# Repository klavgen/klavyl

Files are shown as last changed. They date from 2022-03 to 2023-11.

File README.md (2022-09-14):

# Klavyl: handwired mechanical keyboard

<p align="center">
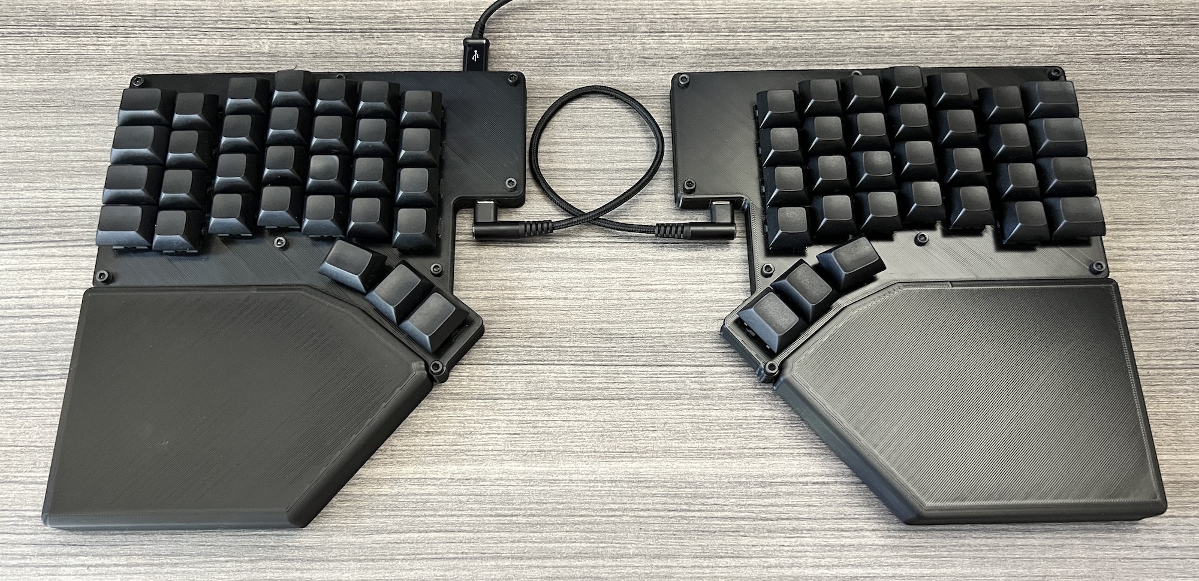
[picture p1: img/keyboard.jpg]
Klavyl keyboard

</p>

**Klavyl** is a [Klavgen](https://github.com/klavgen/klavgen)-based, handwired, hotswappable, split, ortholinear,
3D-printed, highly composable mechanical keyboard that has 4 rows and 7 columns, a 3-key thumb fan, is easy to solder,
is low height, and has a palm rest. That's a lot, so let's decompose:

- **handwired**: you don't need to buy or make PCBs
- **MX or Choc switches**: uses either MX or Choc switches (but with MX spacing). Choc is still highly experimental.
- **hotswappable**: uses Kailh hotswap sockets
- **split**: left and right hand halves are separate
- **ortholinear**: keys form a line across rows, rather than staggered where each row is offset
- **3D-printed without supports** on a home FDM printer, with large parts kept simple to minimize the chance of errors
- **low height**: only 11 mm tall, including 2mm top and bottom plates
- **highly composable**: small changes to the layout only require printing a top plate since the switch holders can be
  moved and the wrapped wires can be unwrapped to allow keys to be spaced further apart
- **easy to solder**: uses holders for the Kailh hotswap sockets that allow in-place soldering of the Kailh socket,
  diode and wires; supports bare wires without insulation, because stripping wires is a pain
- **sturdy**: the Kailh socket holders support the top plate to prevent bending
- **4 rows and 7 columns, plus a 3-key thumb fan**: 31 keys per half, 62 total
- **parametrically generated with [Klavgen](https://github.com/klavgen/klavgen)**
- **palm rests**: detachable and optional

I made Klavyl as a personal modification of the excellent [Redox keyboard](https://github.com/mattdibi/redox-keyboard).

The current files are meant for:

- Kailh hotswap sockets (MX or Choc)
- Pro Micro or similar boards of the same size
- USB-C connection between the two halves
- QMK for the firmware
- Printing on a reasonably tuned 3D printer. I used an Ender 3 V2.
- M3 screws with inserts that are melted into the board

If you want a different config, let me know by filing an issue.

# STLs

You can find STLs in:

- [`/stl_mx`](stl_mx/) for MX switches
- [`/stl_choc`](stl_choc/) for Choc switches (highly experimental)

# More pictures of the MX version

Back photo, showing the low height of 11 mm and the cable connections:

<p align="center">
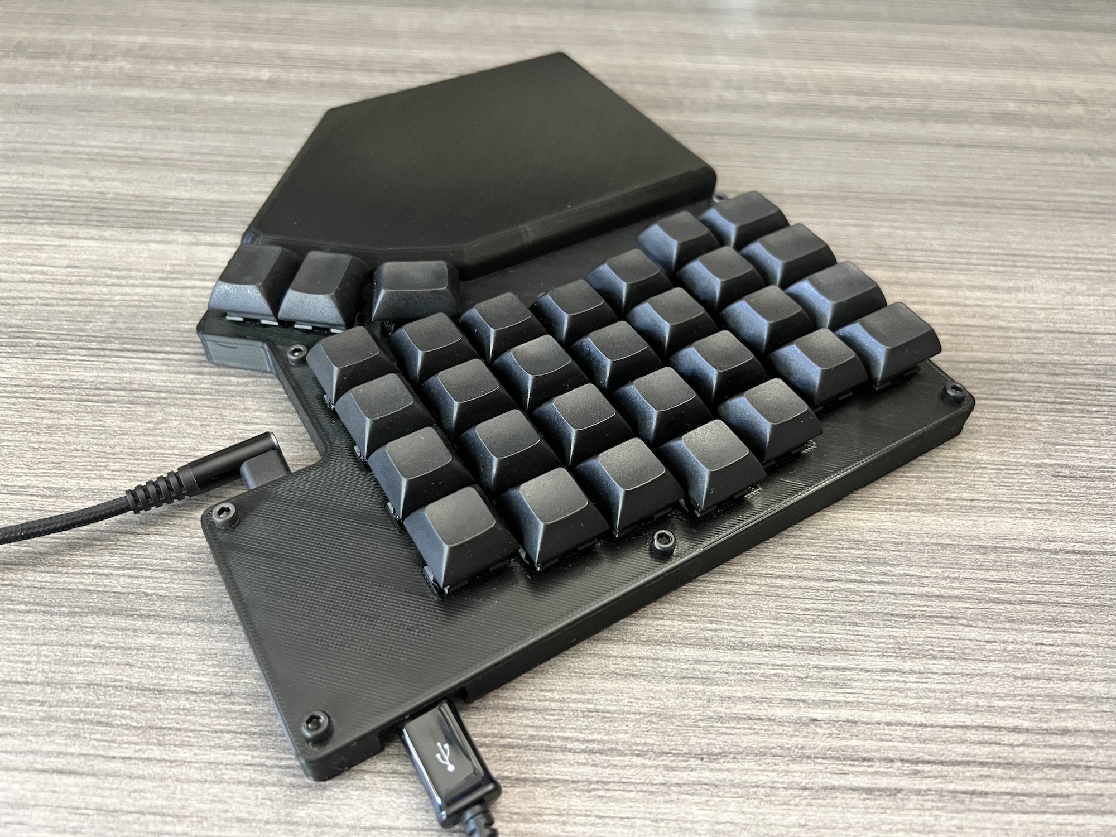
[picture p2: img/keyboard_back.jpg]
Klavyl keyboard

</p>

Front of 3D model, showing the top with switch holes, the bottom, the palm rest, and the USB-C jack holder:

<p align="center">
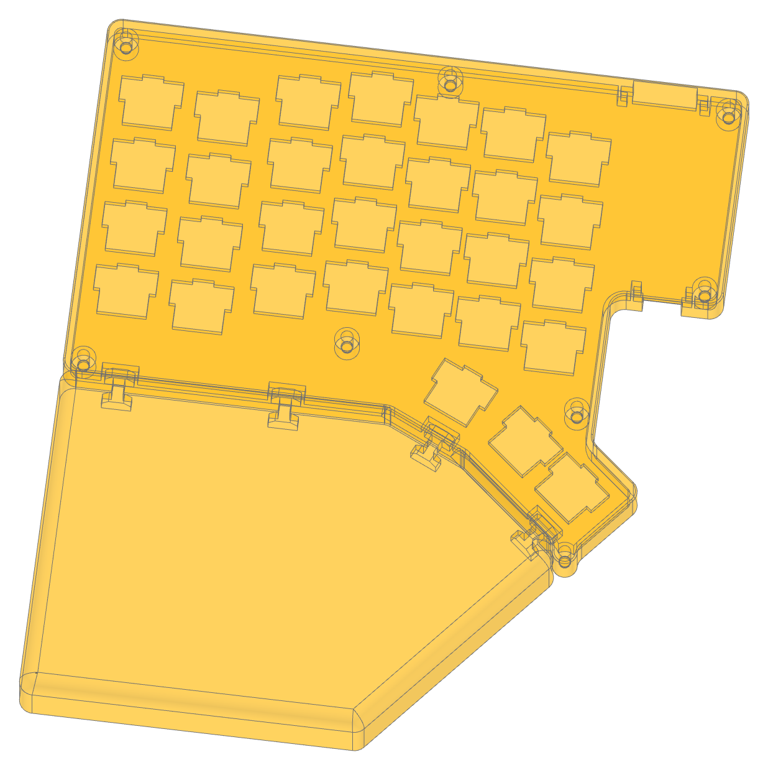
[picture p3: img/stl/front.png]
Front

</p>

Back of 3D model, showing the cutout for the Pro Micro:

<p align="center">
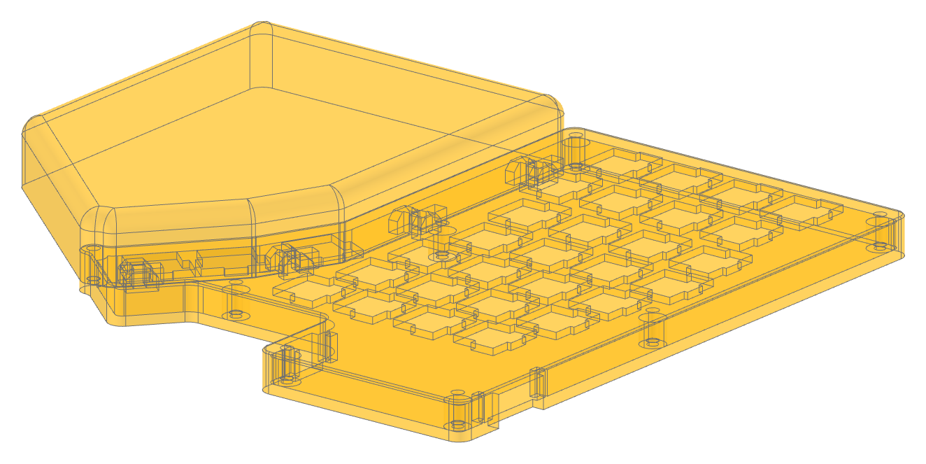
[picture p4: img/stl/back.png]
Back

</p>

Front of 3D model, showing all the components (top, bottom, palm rest, switch holders, Pro Micro holder, USB-C jack
holder):

<p align="center">
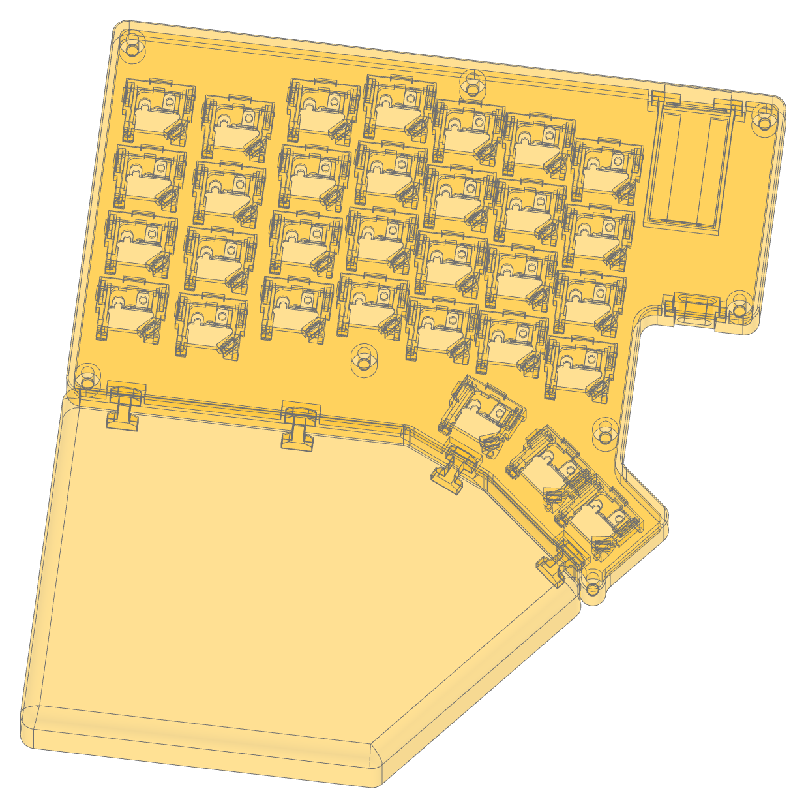
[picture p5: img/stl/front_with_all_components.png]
Front with all components

</p>

# Generating STLs and adjusting the layout

To see how Klavyl is built and adjust it, as well as re-generate the output `.stl` files (from the `stl` directory),
check out and run the [`klavyl.py`](klavyl.py) file.

Modify the `use_choc` variable to generate Choc holes and switch holders.

# Purchased parts

These are the parts you need. The Amazon links is what I used and they are non-affiliate.

| Quantity | Part | Notes |
| ---: | --- | --- |
| 62 | MX switches | I use Boba U4, from AliExpress |
| 62 | MX keycaps | 48 1u keycaps and 14 1.25u keycaps |
| 62 | Kailh hotswap sockets | [Amazon link](https://www.amazon.com/gp/product/B096WZ6TJ5) for MX; the Choc hotswap sockets I got from AliExpress |
| 62 | 1N4148 diodes | [Amazon link](https://www.amazon.com/gp/product/B06XB1R2NK) |
| 2 | Female USB-C socket | [Adafruit link](https://www.adafruit.com/product/5180) |
| 2 | 4.7 kOhm resistors | [Amazon link](https://www.amazon.com/gp/product/B07HDFHPP3) |
| 2 | Arduino Pro Micro microcontrollers | [Amazon link](https://www.amazon.com/gp/product/B08BJNV1J3) |
| 1 | USB-C to USB-C cable | [Amazon link](https://www.amazon.com/gp/product/B0B5QJTT8M) |
| 1 | Micro USB cable | Make sure it's not a power-only cable |
|  20 feet | 26 gauge or smaller solid core wire | You can also use enameled or stranded wires, but it will be more painful |
| ~20 | Rubber bumpers to stabilize the board | [Amazon link](https://www.amazon.com/gp/product/B08MDW52SC) |
| 12 | M3 6 or 8 mm screws | [Amazon link](https://www.amazon.com/gp/product/B07VRC5RJ8) |
| 12 | M3 inserts | [Amazon link](https://www.amazon.com/gp/product/B01IYWTCWW) |
| Much | PLA for 3D printing most parts | I used a mix of Hatchbox and Overture, but any should do |
| Some | ABS for 3D printing switch holders | I used Hatchbox |

# Tools

You need:

- Soldering iron and everything around it: solder, safety glasses, ventilation, etc.
- Tweezers
- Wire stripper, unless you are going to strip manually or will use bare wire for the rows/columns and only use
  insulated wire for the Pro Micro and USB-C jacks

# 3D printed parts

All the parts for 3D printing are in the [`stl_mx`](stl_mx/)/[`stl_choc`](stl_choc/) directories. They have been tested
on an Ender 3 V2 and therefore the tolerances may not work for your printer. If that's the case, let me know by filing
an issue in the project.

Below I discuss MX version, but everything is the same for the Choc versions in the [`stl_choc`](stl_choc/) directory.

You should be able to print everything in PLA, expect the switch holders for which I recommend ABS because you'll be
soldering on them and the soldering iron can very easily melt PLA.

This is what you should print:

| Quantity | File | Notes |
| ---: | --- | --- |
| 1 | `keyboard_top.stl` | Print in normal orientation for the left hand |
| 1 | `keyboard_top.stl` | Print **mirrored** for right hand |
| 1 | `keyboard_bottom.stl` | Print in normal orientation for the left hand |
| 1 | `keyboard_bottom.stl` | Print **mirrored** for right hand |
| 1 | `palm_rest.stl` | Print in normal orientation for the left hand |
| 1 | `palm_rest.stl` | Print **mirrored** for right hand |
| 62 | `switch_holder.stl` | Print file as is, without supports, with the flat side facing down. Use ABS |
| 4 | `connector.stl` | Print file as is, without supports |
| 2 | `controller_holder.stl` | Ensure your Pro Micros actually fit |
| 2 | `usbc_jack_holder.stl`  | Ensure your USB-C jacks actually fit |

## Keyboard bottom

File [`keyboard_bottom.stl`](stl_mx/keyboard_bottom.stl). The bottom part, for the left hand.

<p align="center">
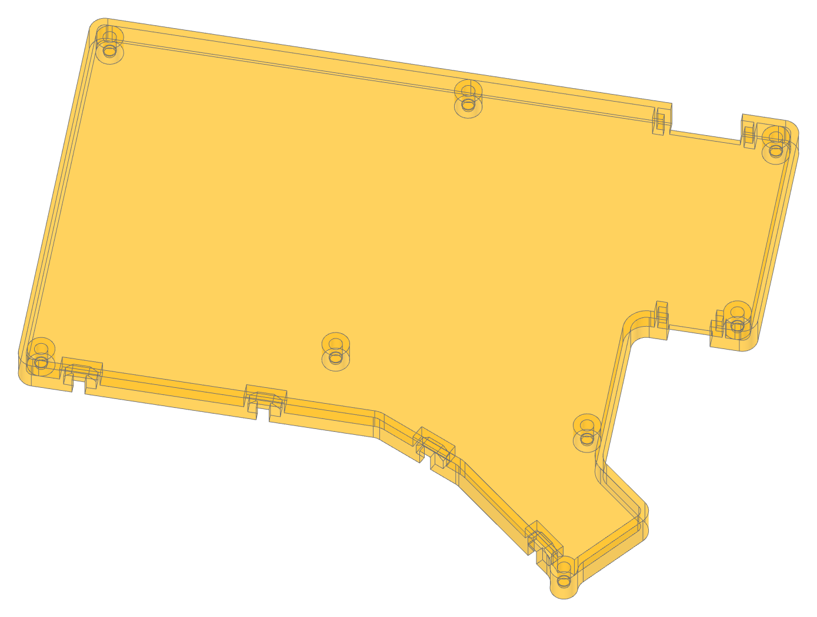
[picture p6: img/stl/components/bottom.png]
Bottom

</p>

## Keyboard top

File [`keyboard_top.stl`](stl_mx/keyboard_top.stl). The top plate, for the left hand. It is flat with simple holes so
that it can be made with a laser cutter or a CNC machine

<p align="center">
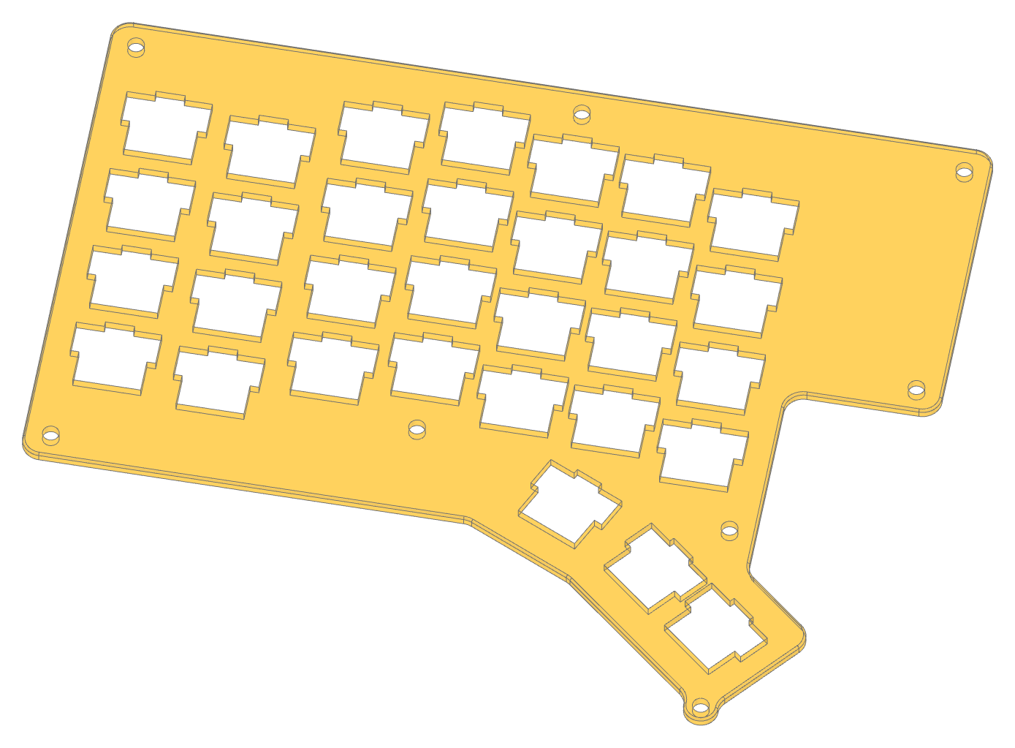
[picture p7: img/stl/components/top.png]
Top

</p>

## Palm rest

File [`palm_rest.stl`](stl_mx/palm_rest.stl). The palm rest which attaches to the bottom via connectors. It can also be
fused with the bottom, see below.

<p align="center">
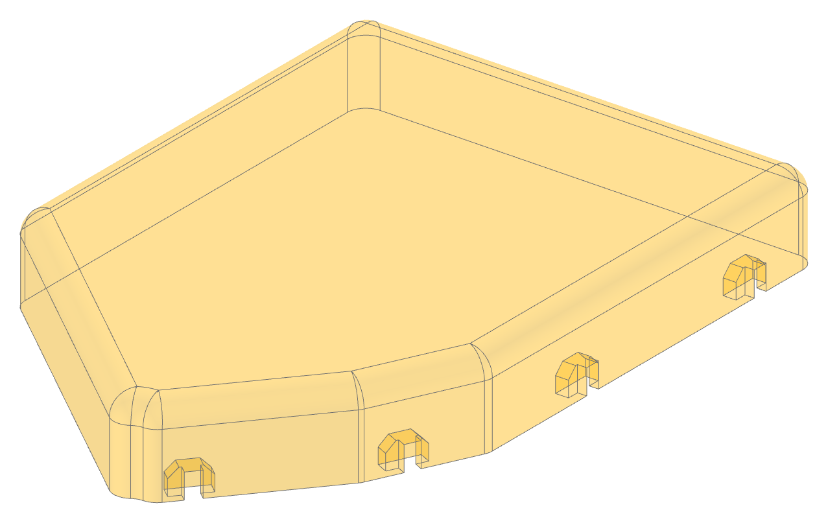
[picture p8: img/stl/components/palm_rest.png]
Palm rest

</p>

## Switch holder

File [`switch_holder.stl`](stl_mx/switch_holder.stl). Holds the Kailh MX hotswap socket and allows you to solder the
diode, column and row wires in-place. Print it the way it's oriented in the STL, with the flat side (that has a small
hole) on the printing plate.

**Note**: print switch holders in ABS since you'll be soldering on them.

<p align="center">
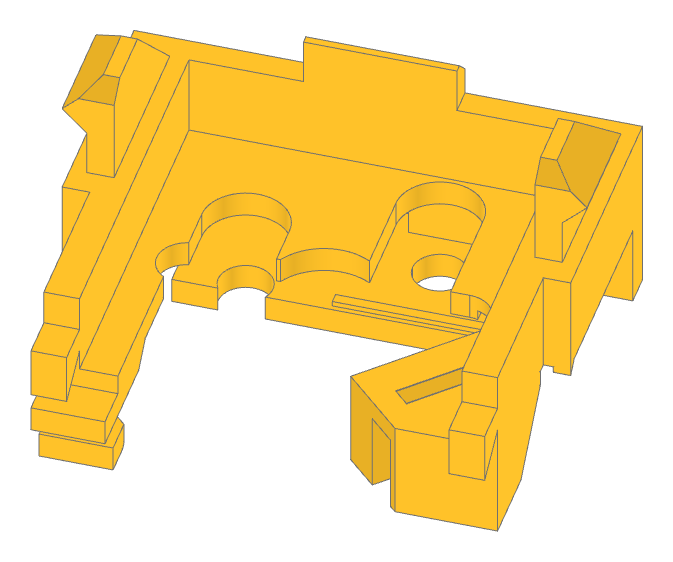
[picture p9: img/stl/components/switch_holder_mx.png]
Switch holder

</p>

## Pro Micro controller holder

File [`controller_holder.stl`](stl_mx/controller_holder.stl). Holds the Arduino Pro Micro controller.

<p align="center">
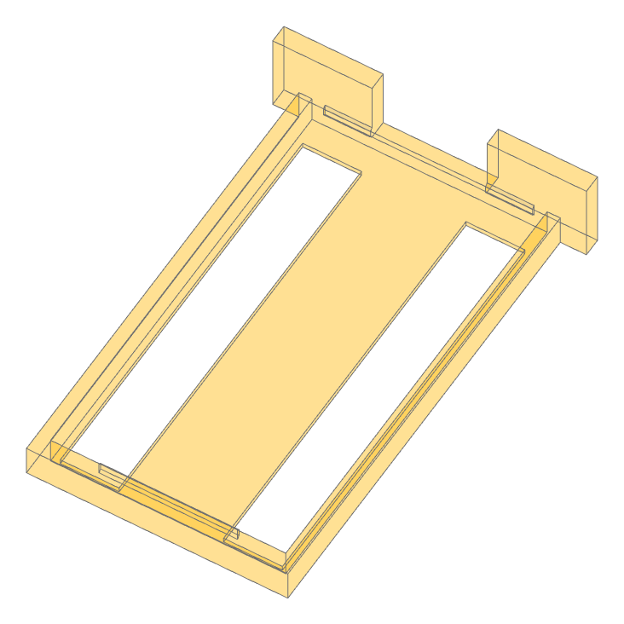
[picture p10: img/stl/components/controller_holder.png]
Pro Micro holder

</p>

## USB-C jack holder

File [`usbc_jack_holder.stl`](stl_mx/usbc_jack_holder.stl). Holds the USB-C socket.

<p align="center">
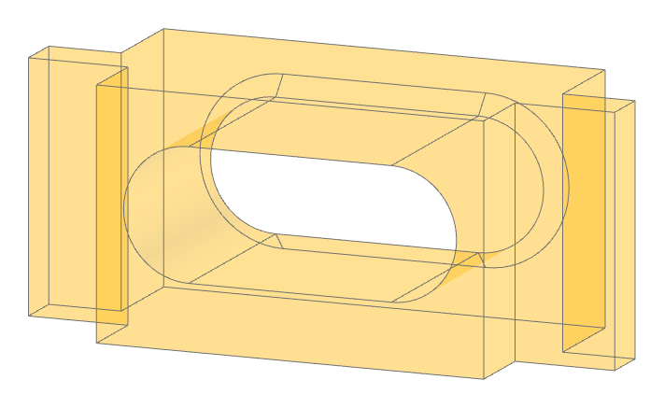
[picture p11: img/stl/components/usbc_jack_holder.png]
USBC jack holder

</p>

## Connector

File [`connector.stl`](stl_mx/connector.stl). Connects the bottom to the palm rest.

<p align="center">
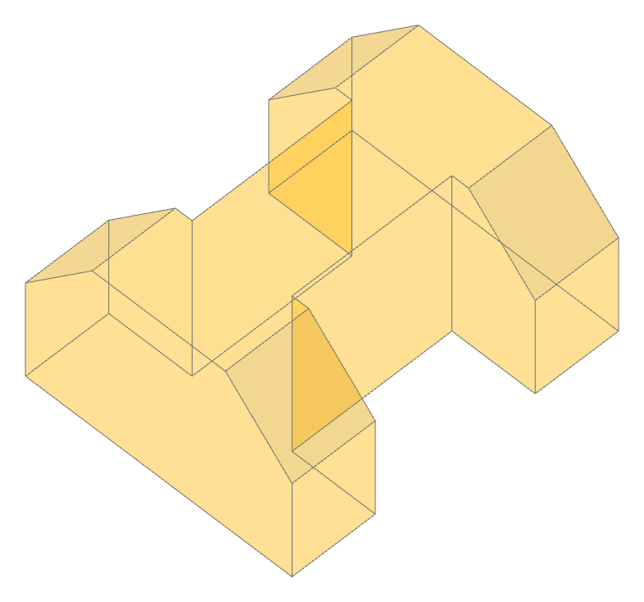
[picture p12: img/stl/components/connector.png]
Connector

</p>

# Building

## Build the left side

1. Strip wires completely for rows and columns, making sure they are about 2x the size of the plate due to wrapping. Do
   not leave insulated wire at the end like I did.

1. Row by row, insert the socket holders, and wrap the row wires:

<p align="center">
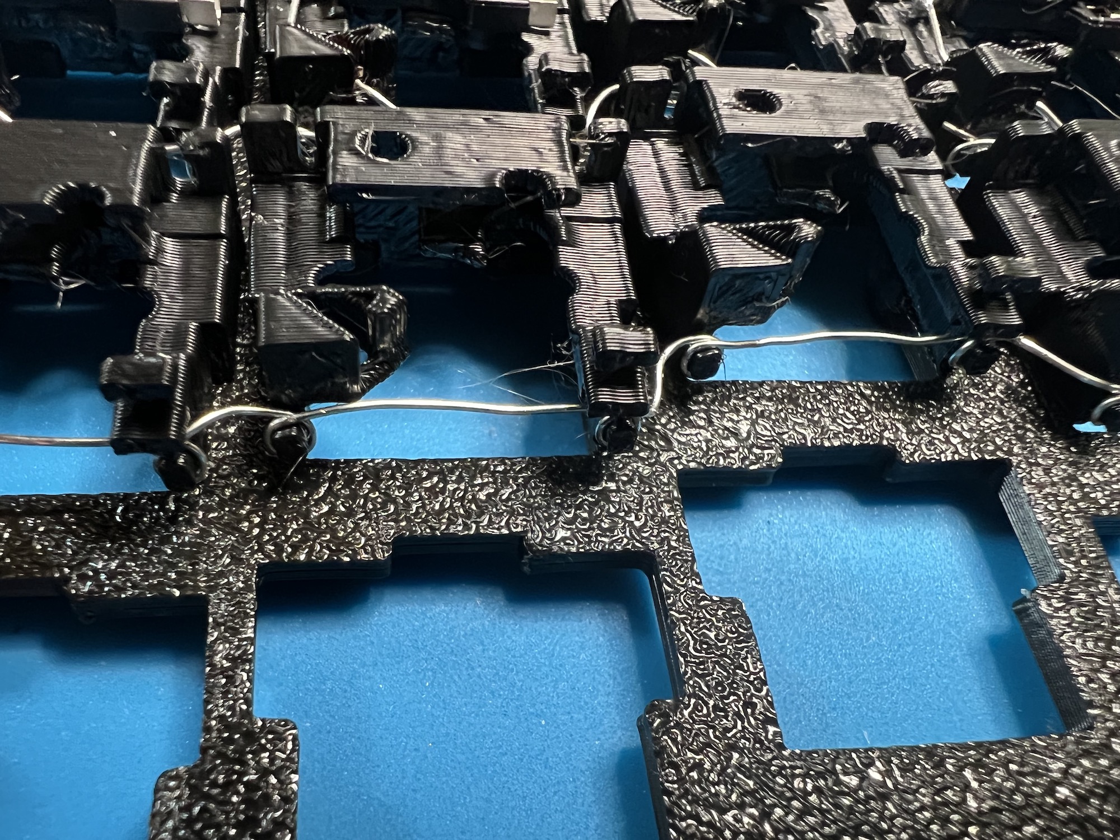
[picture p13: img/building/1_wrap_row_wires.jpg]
Wrap row wires

</p>

**Note**: the 3 keys on the thumb fan are a separate row

3. Place the diodes, bending the legs on the back to hold them in place:

<p align="center">
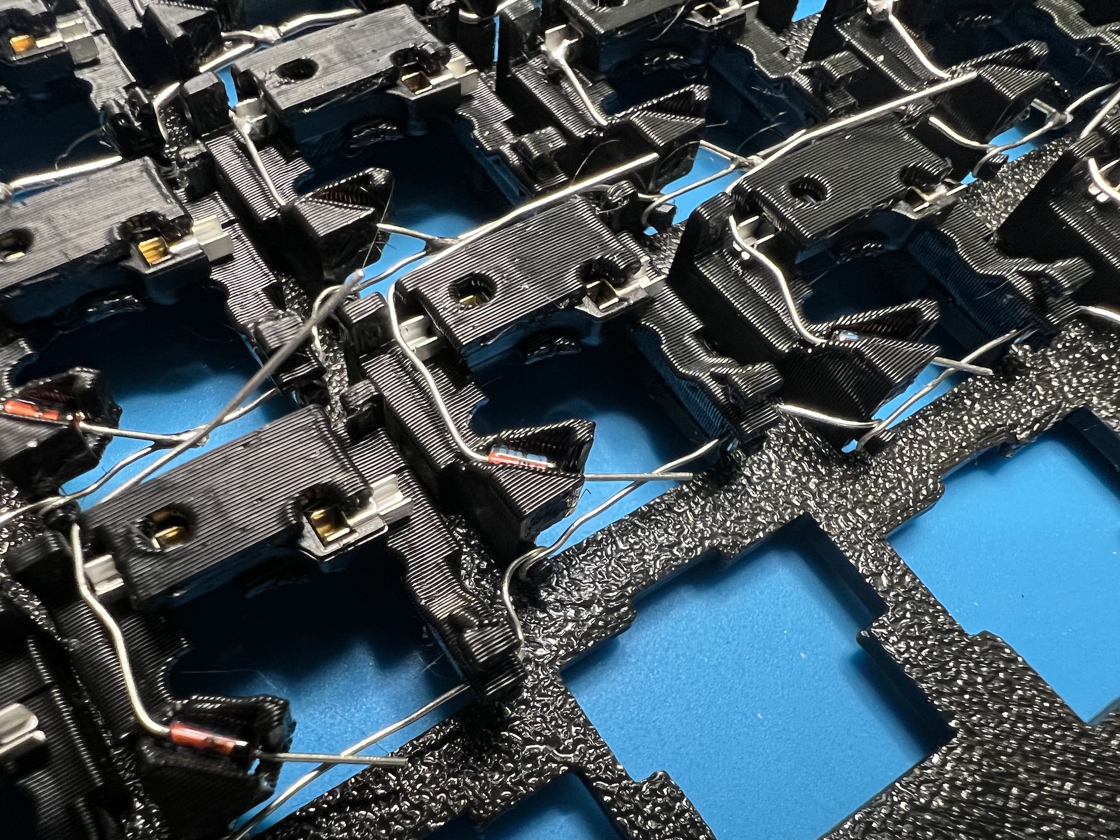
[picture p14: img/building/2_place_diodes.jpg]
Place diodes

</p>

4. Solder the diodes and row wires, and cut the extra diode legs:

<p align="center">
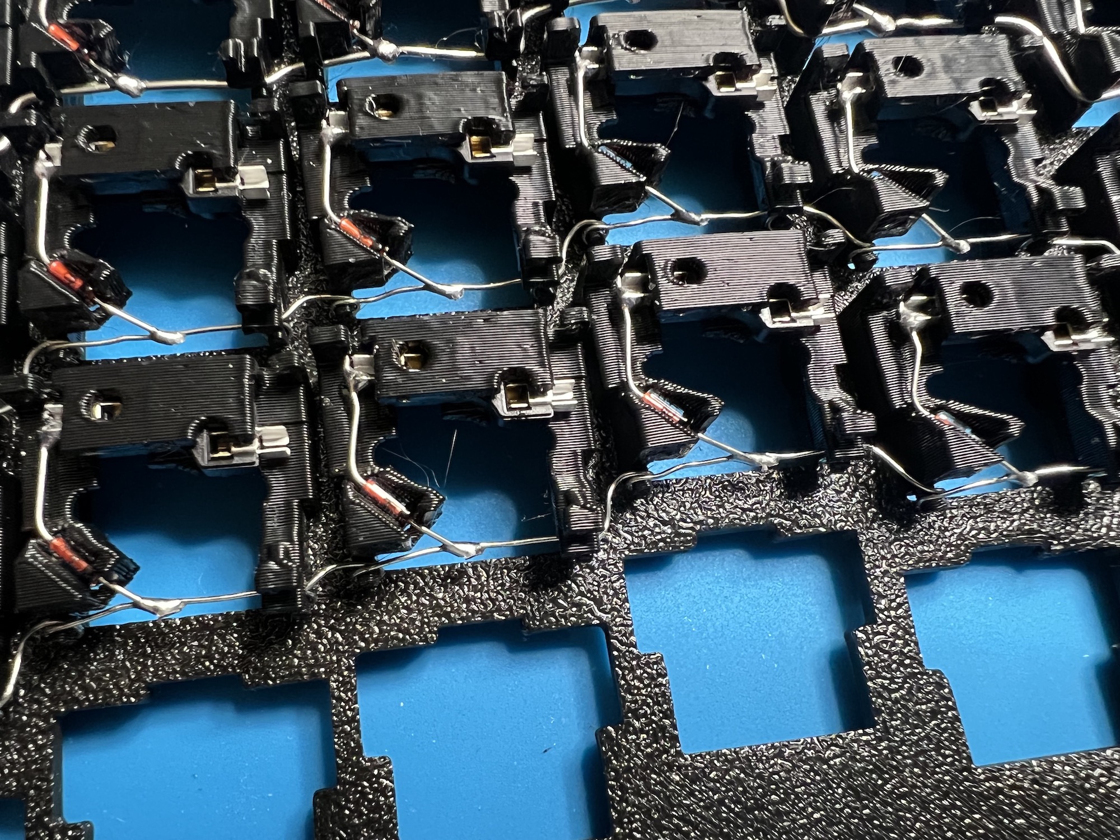
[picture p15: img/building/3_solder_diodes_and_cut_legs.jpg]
Solder diodes and cut their legs

</p>

5. Wrap and solder the column wires. Note that you should not have the top and left dangling wires, as it's much better
   to first solder wires to the Pro Micro and then solder those wires to the rows/columns:

<p align="center">
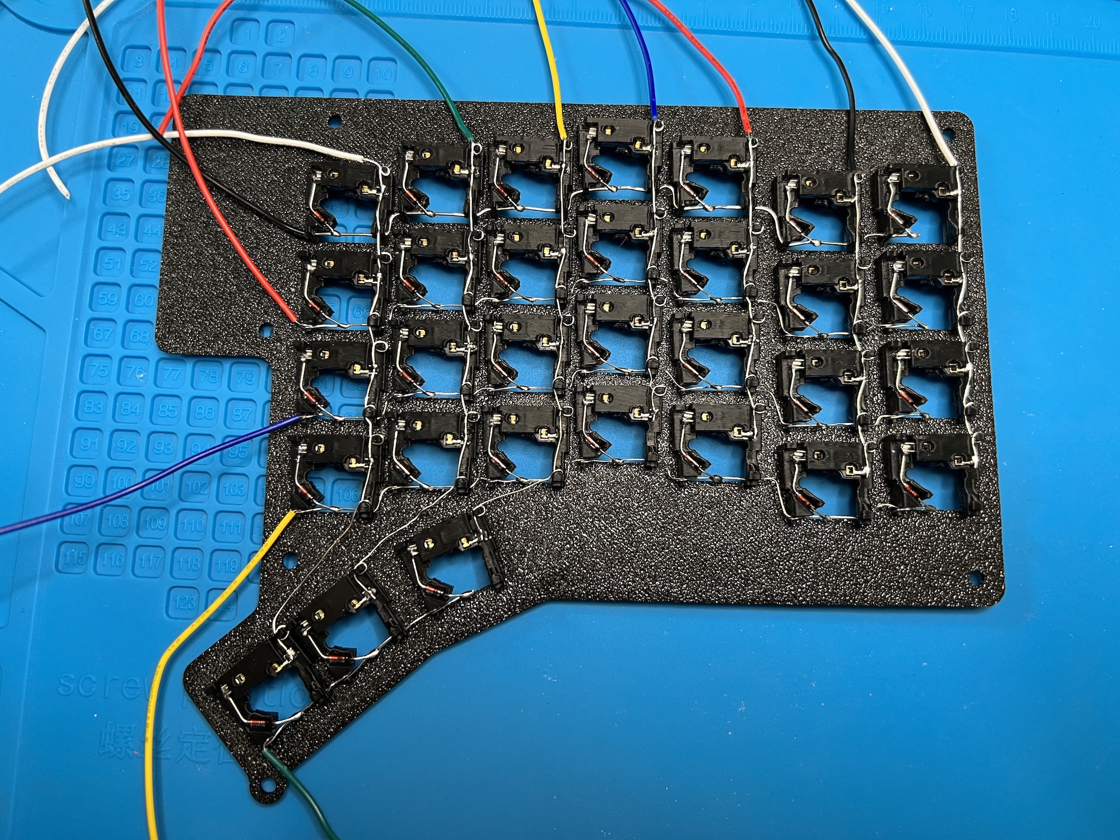
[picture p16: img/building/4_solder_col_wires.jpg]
Wrap and solder column wires

</p>

**Note**: the 3 keys on the thumb fan need to be wired to columns 5, 6, and 7 (see the picture).

6. Wire the USB-C jack to the Pro Micro. The actual wiring doesn't matter as long as it's consistent on both halves. I
   use the following:

   - VCC pad to VCC
   - D+ pad to 3/PD0
   - D- pad to 2/PD1
   - G pad to GND

1. Solder USB-C jack resistors **ON ONE SIDE ONLY**. Solder two resistors, one between the 3/PD0 and VCC wires, and one
   between the 2/PD1 and VCC wires. This was pretty challenging to do given the short wires and limited space. Use
   electrical tape to insulate the connections.

1. Solder long wires to the controller itself with the other ends dangling. See the next step for which holes on the Pro
   Micro to use. Don't do as in the picture above where I did the reverse and had the wires soldered to the rows/columns
   first.

1. Route the controller wires and solder them to the row and column wires. This is the trickiest part. Your result may
   look like this but it may be even better to route the wires between keys, rather than only on the top/side. Klavyl
   uses the same wiring as
   [the Redox keyboard](https://github.com/mattdibi/redox-keyboard/blob/master/redox/pcb/Redox-schematic.pdf). You have
   to solder the columns mirrored. On both sides, column 1 is the 4-row column that is farthest away from the thumb fan.
   Row 0 is always the top row. The wiring needs to be:

   - Column 1: A2/PF5
   - Column 2: A1/PF6
   - Column 3: A0/PF7
   - Column 4: 15/PB1
   - Column 5: 14/PB3
   - Column 6: 16/PB2
   - Column 7: 10/PB6
   - Row 1: 4/PD4
   - Row 2: 6/PD7
   - Row 3: 7/PE6
   - Row 4: 8/PB4
   - Row 5: 9/PB5

This is an older picture from when Klavyl still used TRRS jacks, but you get the idea:

<p align="center">
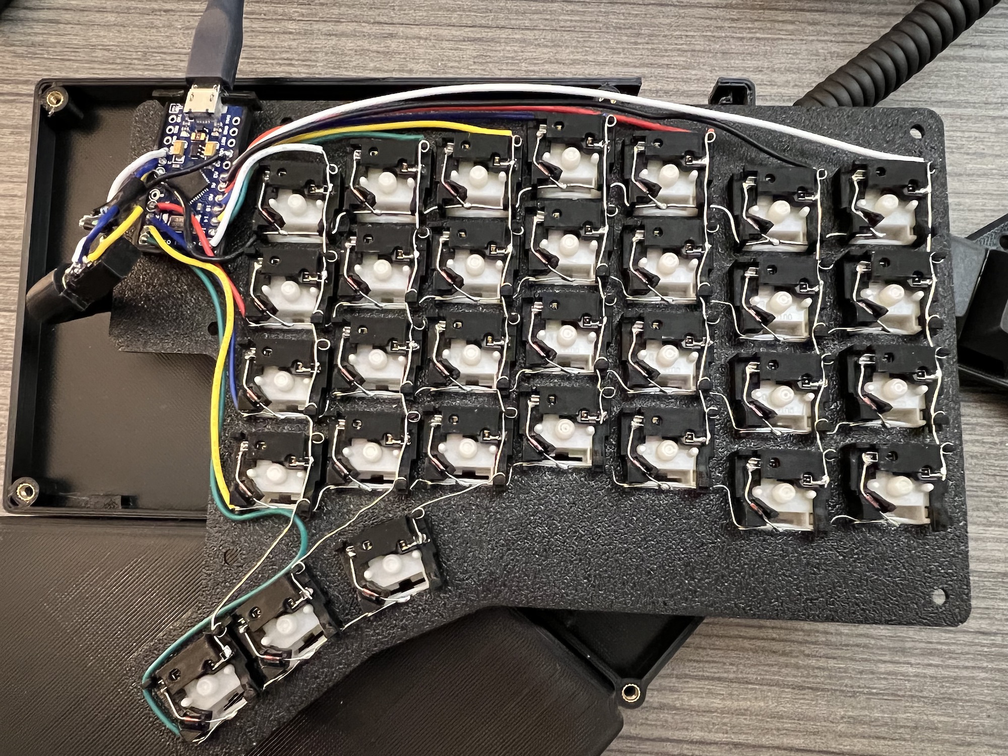
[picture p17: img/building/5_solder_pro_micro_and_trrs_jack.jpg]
Solder Pro Micro and TRRS jack

</p>

10. Use the soldering iron to melt the M3 inserts into the bottom. I used a temperature of 200-250 degrees F. See
    picture above.

## Build the right side

It's the same as the left, but mirrored. Watch out for having resistors only on one side.

# Flashing QMK

**Note**: the default layout is very custom to me. It is meant for a Mac and has a lot of unexpected changes including
swapping around shifted and unshifted keys. Make sure to modify it.

1. Grab a recent version of [QMK](https://github.com/qmk/qmk_firmware). I used commit
   [779c7debcfff1a4a3ad578a0c12bdd50cba11039](https://github.com/qmk/qmk_firmware/tree/779c7debcfff1a4a3ad578a0c12bdd50cba11039).
   Follow the QMK guide to get it set up and compiling.

1. Copy the `klavyl` dir from `qmk/keyboards` in this repo to the `keyboards` dir in QMK.

1. Add a new keymap or adjust the default layout to suit you.

1. Compile and flash with `make klavyl:default:avrdude` (replace `default` with your keymap if you made a custom one).
   You have to reset your Pro Micro to enter bootloader mode by shorting quickly once RST and GND.

Once you flash both halves the first time, later on you only need to flash the half that connects by USB to your
computer. The other half just reports what keys are pressed. Only the primary half decides what this means in terms of
symbols sent to the computer.

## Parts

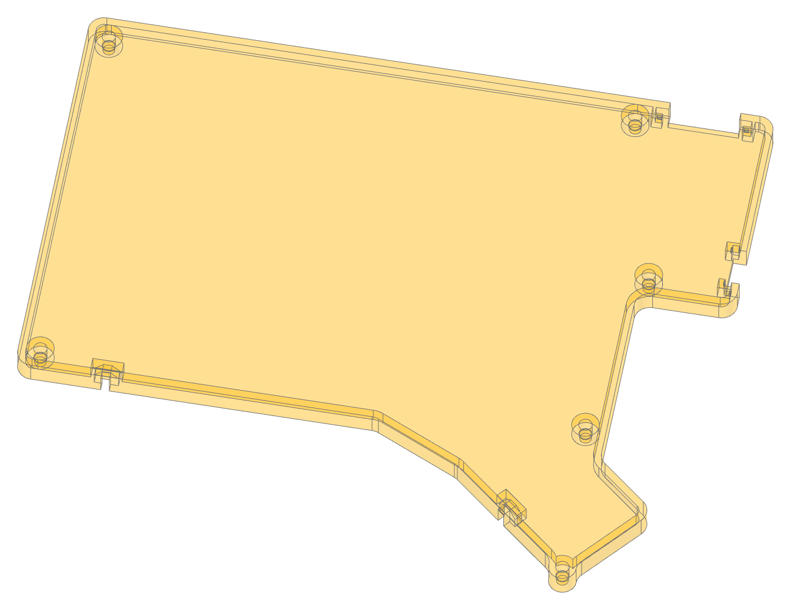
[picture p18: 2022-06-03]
img/components/bottom.png

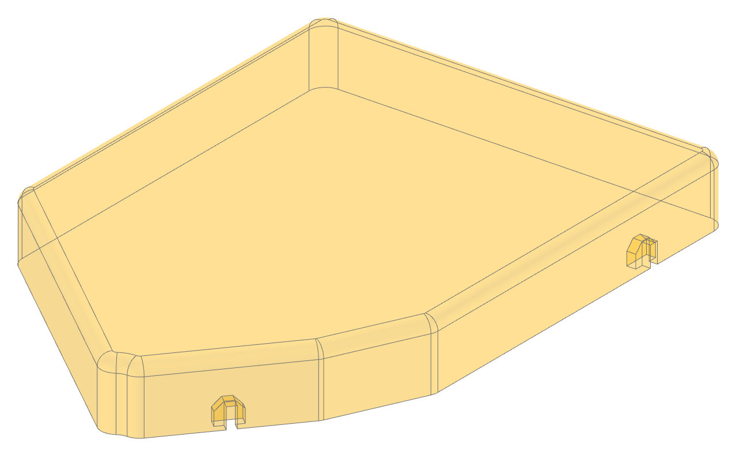
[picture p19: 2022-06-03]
img/components/palm_rest.png

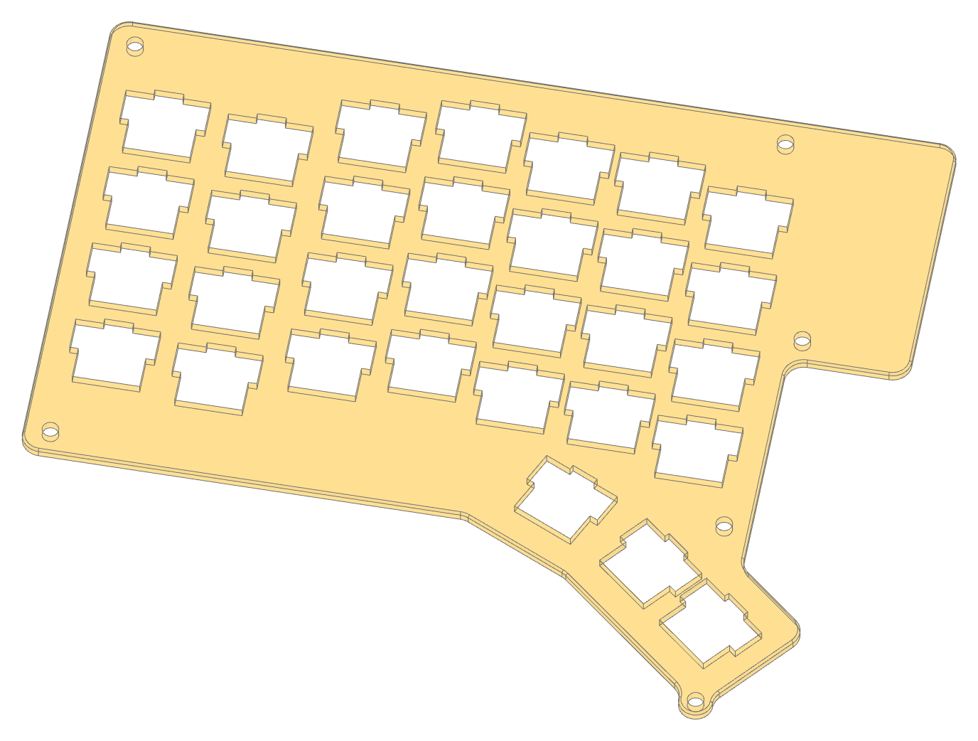
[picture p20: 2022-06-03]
img/components/top.png

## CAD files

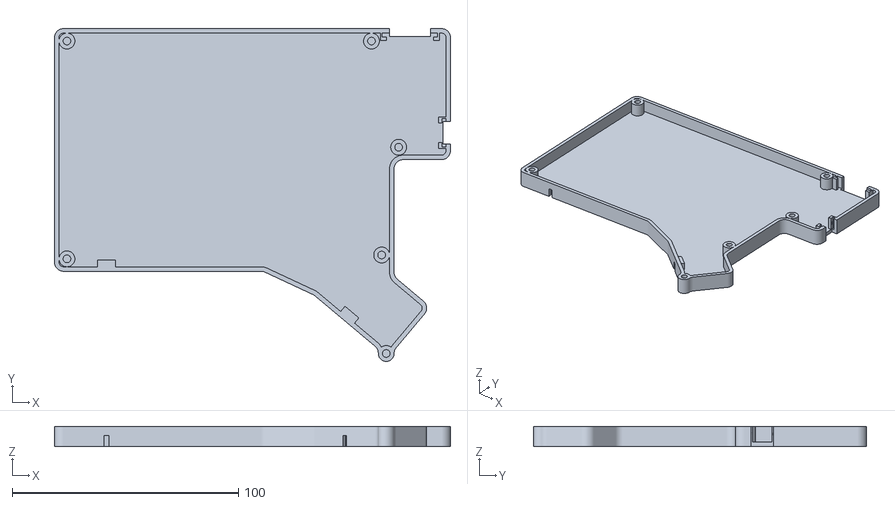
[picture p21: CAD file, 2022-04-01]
stl/keyboard bottom.stl
174.9 x 147.0 x 9.00

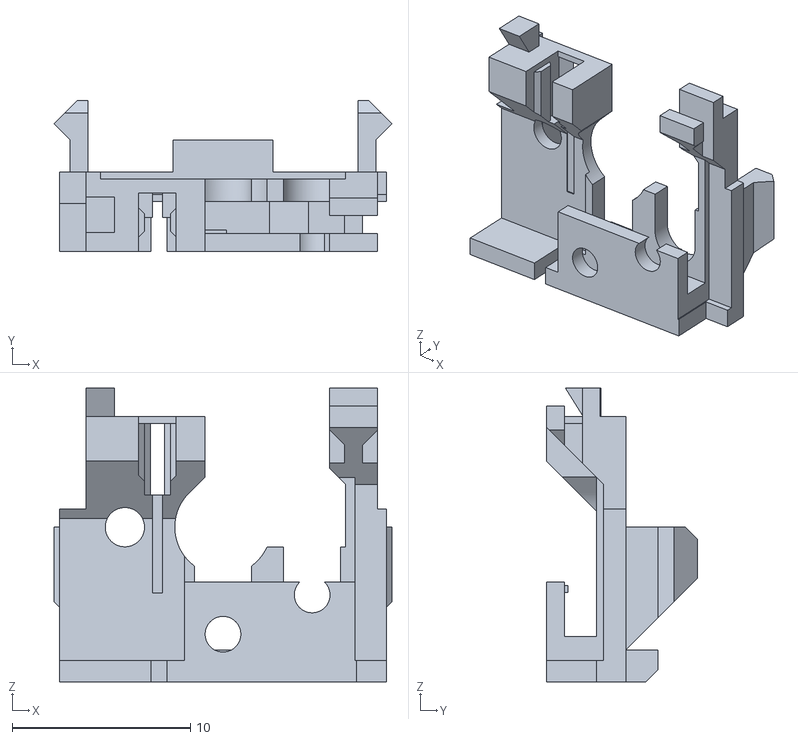
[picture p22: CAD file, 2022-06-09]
stl_choc/switch_holder.stl
18.9 x 8.45 x 16.5

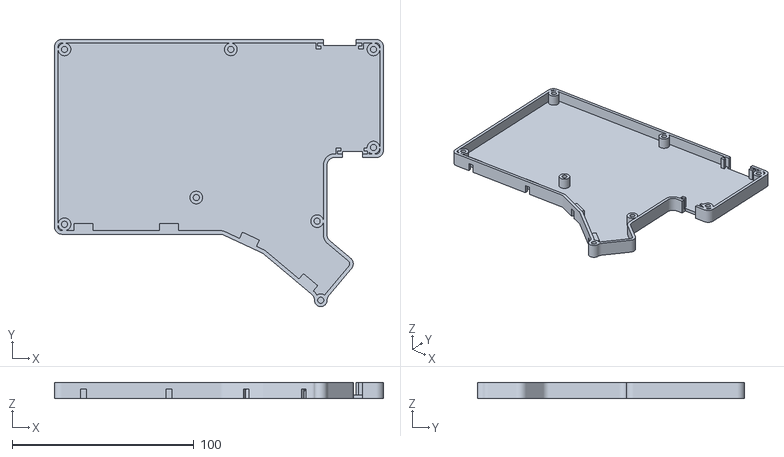
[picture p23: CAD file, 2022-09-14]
stl_mx/keyboard_bottom.stl
181.0 x 147.0 x 9.00

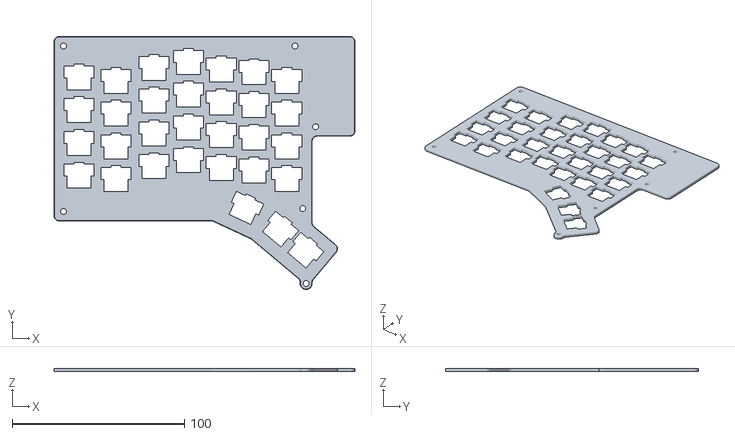
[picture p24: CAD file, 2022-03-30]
stl/keyboard top.stl
174.9 x 147.0 x 2.00

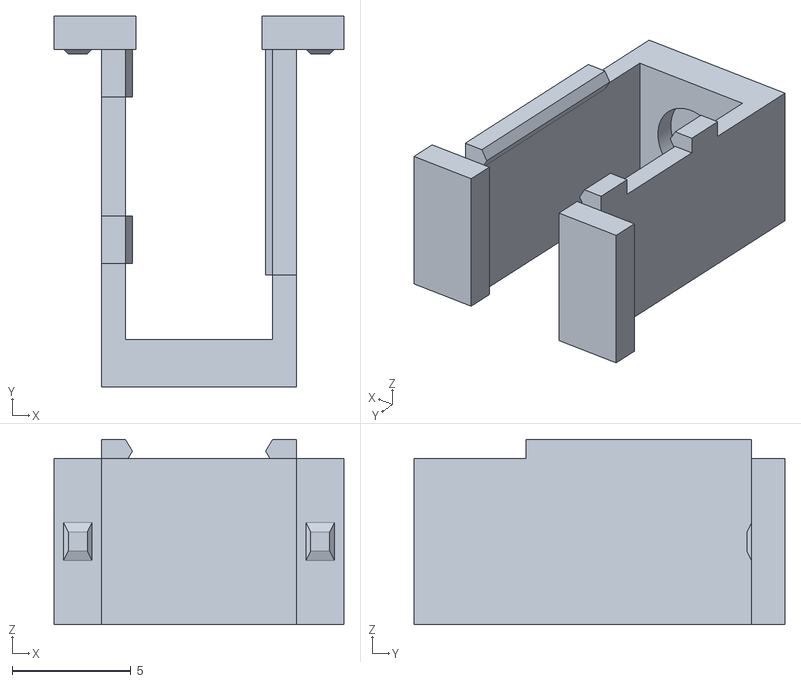
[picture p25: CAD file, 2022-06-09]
stl_choc/trrs_jack_holder.stl
12.2 x 15.6 x 7.80

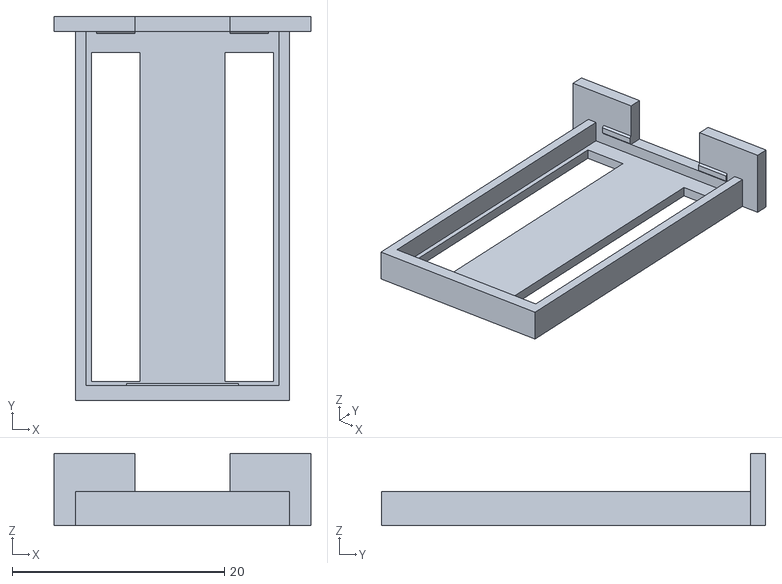
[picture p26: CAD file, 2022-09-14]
stl_mx/controller_holder.stl
24.2 x 36.2 x 6.80

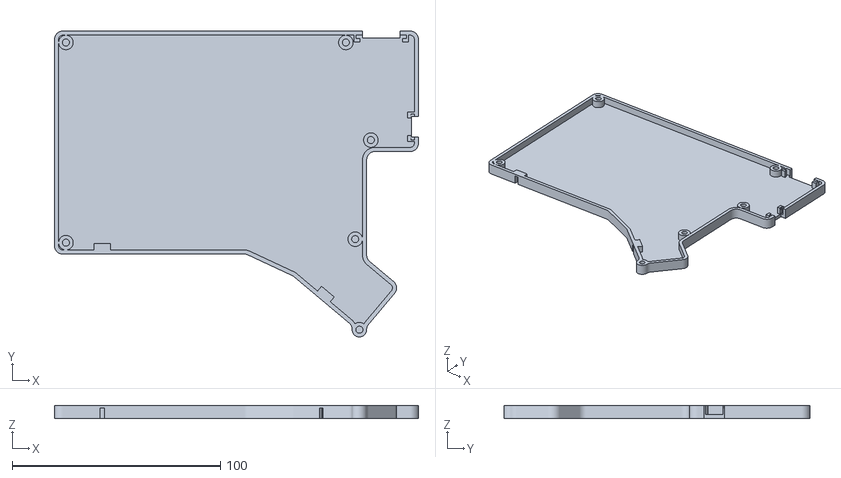
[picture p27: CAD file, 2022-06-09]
stl_choc/keyboard_bottom.stl
174.9 x 147.0 x 6.20

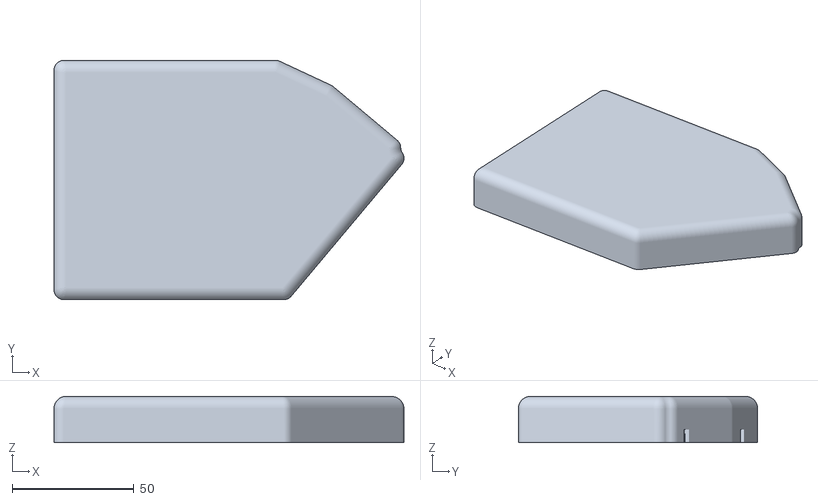
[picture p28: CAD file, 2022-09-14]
stl_mx/palm_rest.stl
143.8 x 98.3 x 19.0

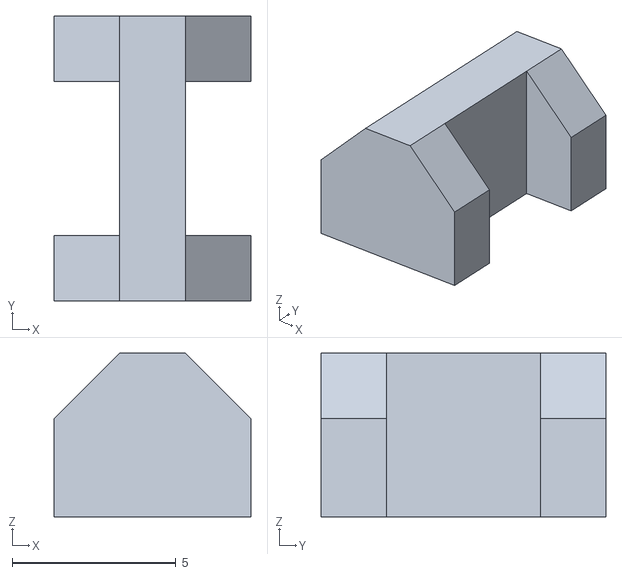
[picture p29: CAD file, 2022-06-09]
stl_choc/connector.stl
6.00 x 8.70 x 5.00

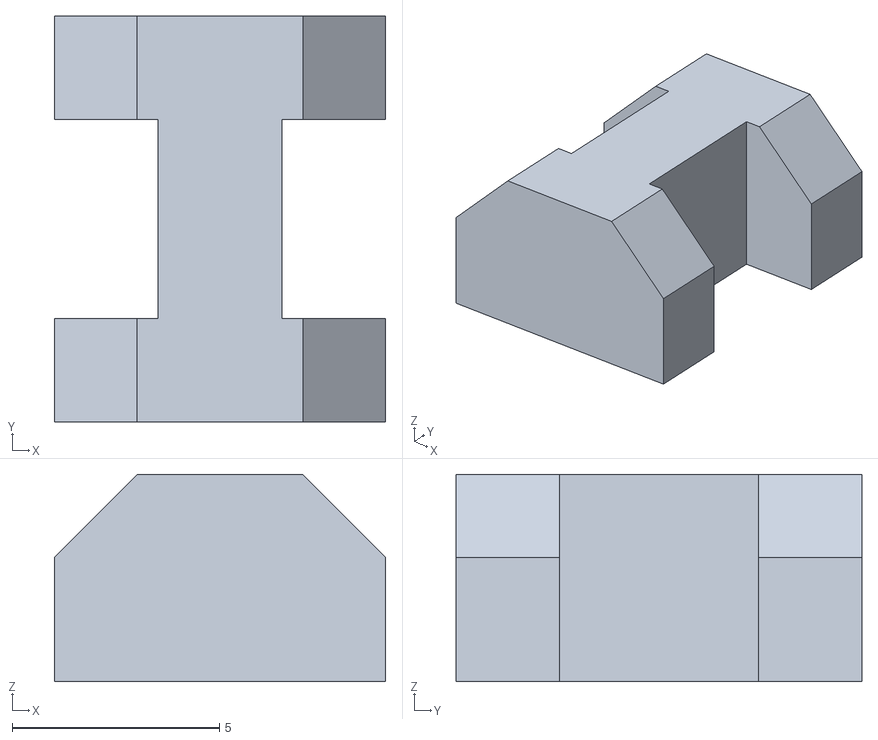
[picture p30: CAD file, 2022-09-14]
stl_mx/connector.stl
8.00 x 9.80 x 5.00

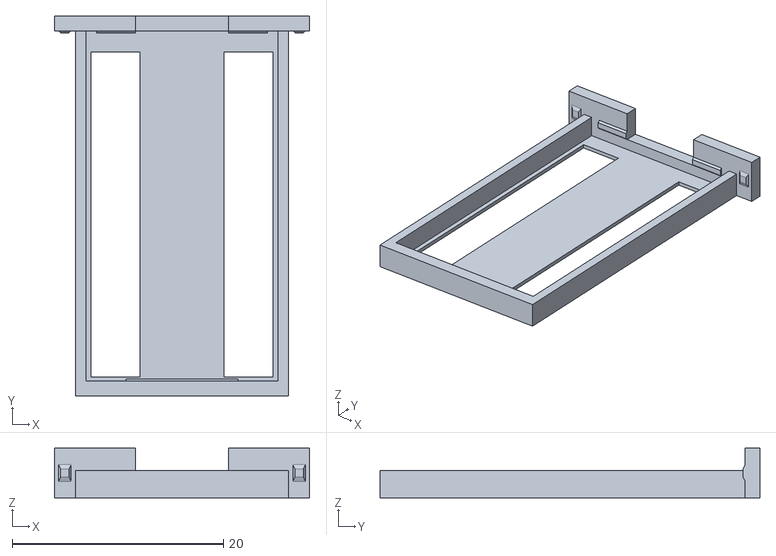
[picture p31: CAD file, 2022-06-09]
stl_choc/controller_holder.stl
24.2 x 36.0 x 4.70

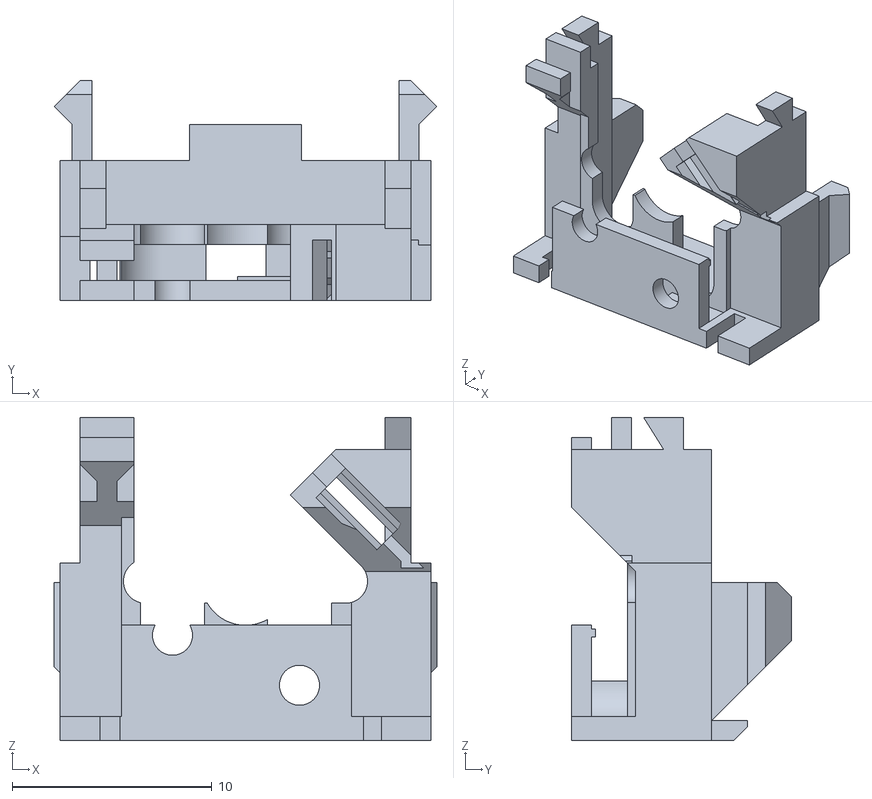
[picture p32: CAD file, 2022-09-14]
stl_mx/switch_holder.stl
19.1 x 11.0 x 16.2

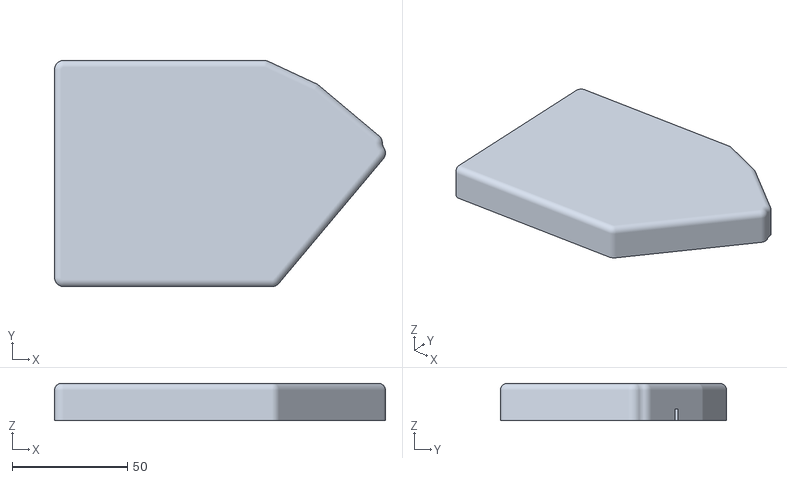
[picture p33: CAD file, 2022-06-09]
stl_choc/palm_rest.stl
143.8 x 98.3 x 16.2

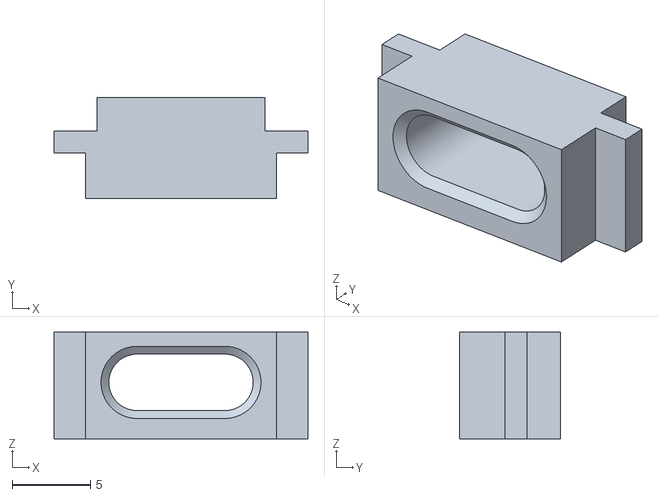
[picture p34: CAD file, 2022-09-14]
stl_mx/usbc_jack_holder.stl
16.2 x 6.45 x 6.80

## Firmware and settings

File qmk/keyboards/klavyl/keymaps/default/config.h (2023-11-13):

#pragma once

// #define USE_SERIAL
#define USE_I2C

#define MASTER_LEFT
// #define MASTER_RIGHT

#define MOUSEKEY_INTERVAL           20
#define MOUSEKEY_DELAY              0
#define MOUSEKEY_TIME_TO_MAX        60
#define MOUSEKEY_WHEEL_MAX_SPEED    MOUSEKEY_MAX_SPEED
#define MOUSEKEY_WHEEL_TIME_TO_MAX  MOUSEKEY_TIME_TO_MAX

#define MOUSEKEY_WHEEL_DELAY 301

#define MOUSEKEY_MAX_SPEED 6

#define MOUSEKEY_WHEEL_INTERVAL 105

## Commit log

2022-04-01 Added generation script
    [controller holder.stl, keyboard bottom.stl, palm rest.stl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]
2022-04-25 Further improve docs and rename STLs
    [controller_holder.stl, keyboard_bottom.stl, palm rest.stl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]
2022-06-09 Support Choc + add black, isort and mdformat
    * Add a switch to support Choc keys
    * Add a pre-commit hook with black, isort and mdformat
2022-06-09 Add Choc STLs and update README
    [connector.stl, controller_holder.stl, keyboard_bottom.stl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]
2022-09-14 Improve QMK config
    * Switch to using I2C
    * Improve keyboard layout
2022-09-14 Update to new version
    * Switch from TRRS to USB-C interconnect
    * Add more screws
    * Move the interconnect so there is more space for wires & resistors
    [connector.stl, controller_holder.stl, keyboard_bottom.stl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]
2022-09-14 Remove shift from angular brackets key as it didn't work
